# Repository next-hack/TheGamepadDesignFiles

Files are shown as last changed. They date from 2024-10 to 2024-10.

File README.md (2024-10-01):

# TheGamepadDesignFiles
 KiCAD design files for The Gamepad, an open source handheld console based on the Arduino Nano Matter Board.

**Notes**
Please use KiCAD 8.0 or later.
Each item in the schematics has its own part number filled so you can easily create the bill of materials.

Building: see https://next-hack.com/index.php/2024/09/21/the-gamepad-an-open-source-diy-handheld-gaming-console

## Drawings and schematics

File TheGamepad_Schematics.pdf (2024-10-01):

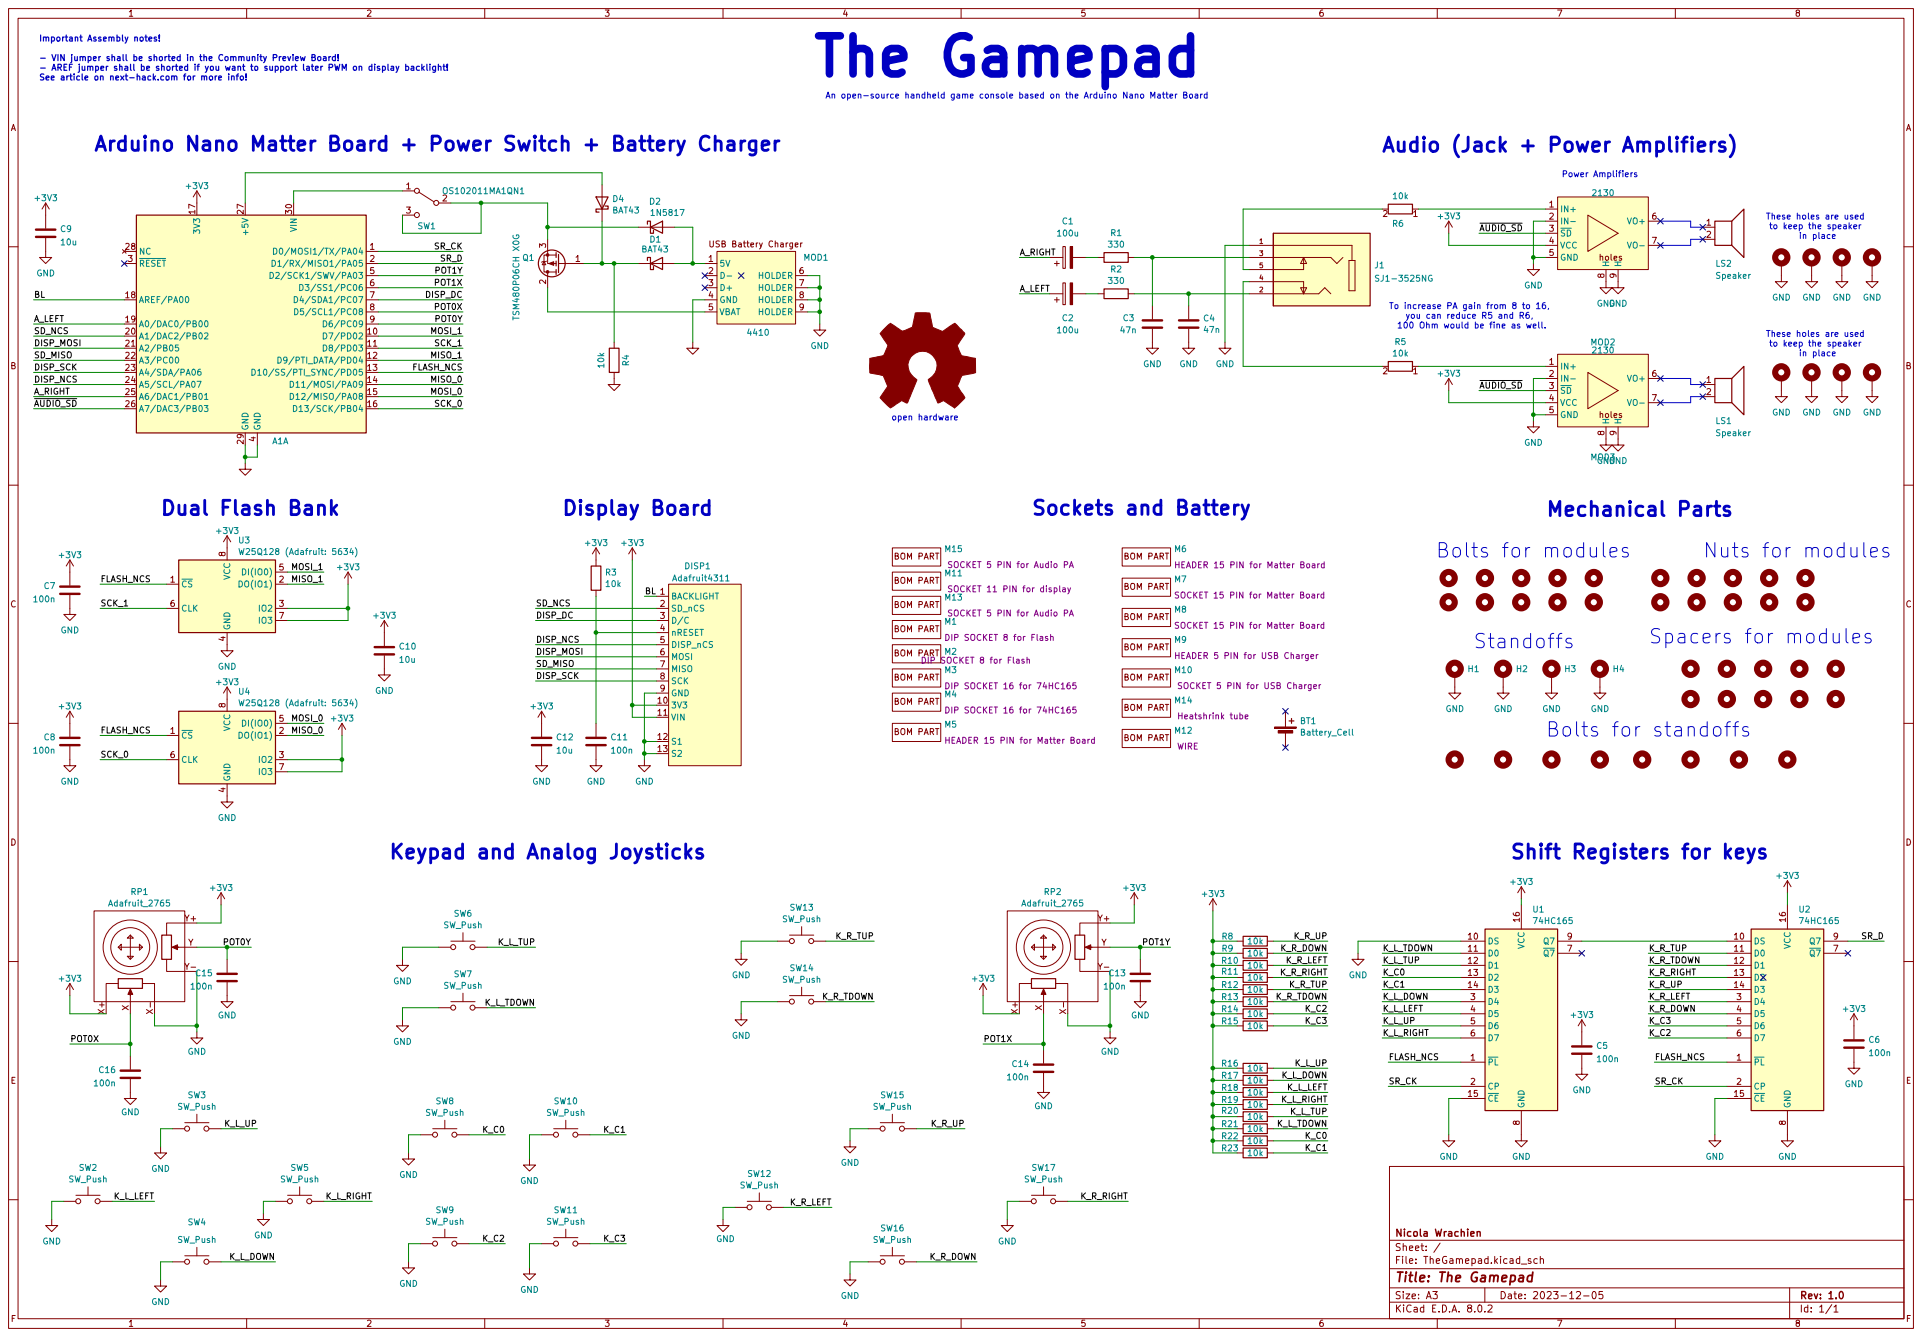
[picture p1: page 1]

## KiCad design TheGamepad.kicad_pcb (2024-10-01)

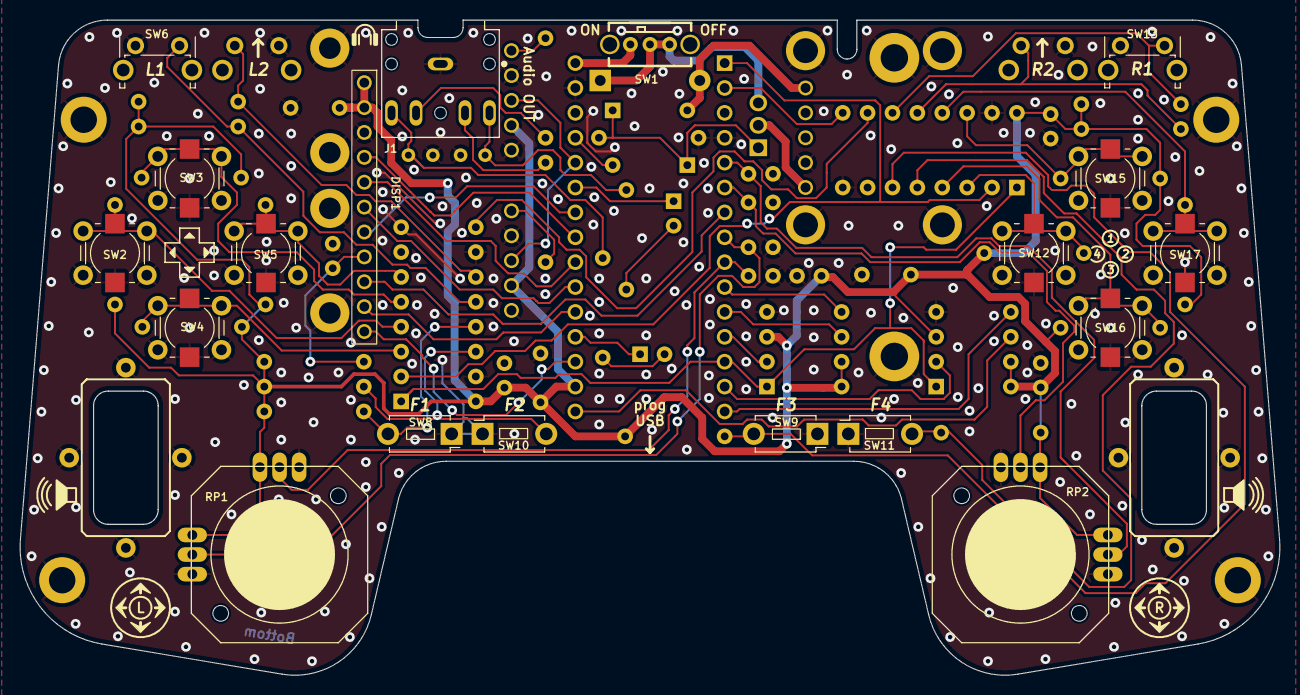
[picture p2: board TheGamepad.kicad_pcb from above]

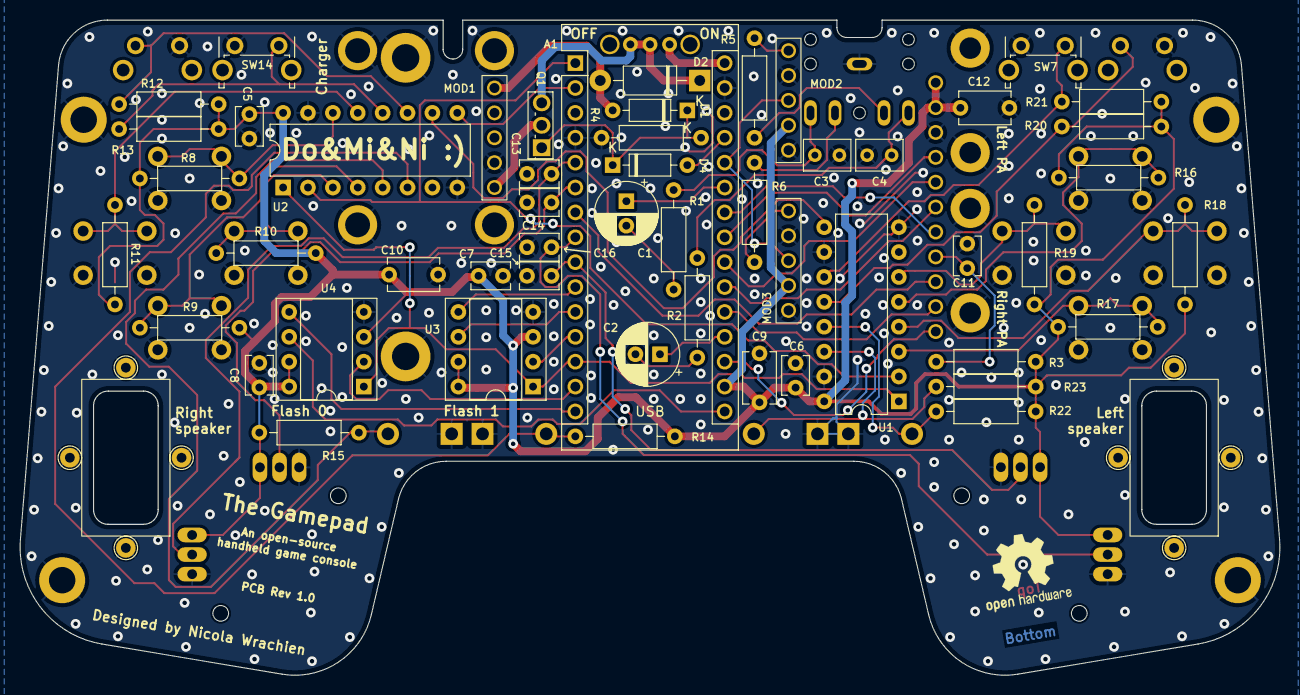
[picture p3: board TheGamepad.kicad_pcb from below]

Board: 2 copper layers, 128.6 x 66.9 mm, 86 parts (61 on the bottom side), 57 nets.

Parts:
A1: Arduino_Nano_Matter_swdio_pins; Arduino_Nano_Matter_WithMountingHoles_TP
C1, C2: 100u; CP_Radial_D6.3mm_P2.50mm
C3, C4: 47n; C_Rect_L4.6mm_W3.0mm_P2.50mm_MKS02_FKP02
C5, C6, C7, C8, C11, C13, C14, C15, C16: 100n; C_Disc_D3.8mm_W2.6mm_P2.50mm
C9, C10, C12: 10u; C_Disc_D5.1mm_W3.2mm_P5.00mm
D1, D4: BAT43; D_DO-35_SOD27_P7.62mm_Horizontal
D2: 1N5817; D_DO-41_SOD81_P10.16mm_Horizontal
DISP1: Adafruit4311
H1, H2, H3, H4: V6516F; MountingHole_2.7mm_M2.5_Pad
H43, H44, H45, H46, H47, H48, H49, H50: MountingHole_Pad; TestPoint_THTPad_D2.0mm_Drill1.0mm
J1: SJ1-3525NG; CUI_SJ1-3525NG
LS1, LS2: Speaker; OWS-091630W50A-8
MOD1: ADAFRUIT_4410
MOD2, MOD3: Adafruit-2130
Q1: TSM480P06CH X0G; TO-251-3_Vertical
R1, R2: 330; R_Axial_DIN0207_L6.3mm_D2.5mm_P10.16mm_Horizontal_ExactSilk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
R3, R4, R5, R6, R8, R9, R10, R11, R12, R13, R14, R15, R16, R17, R18, R19, R20, R21, R22, R23: 10k; R_Axial_DIN0207_L6.3mm_D2.5mm_P10.16mm_Horizontal_ExactSilk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
RP1, RP2: Adafruit_2765
SW1: OS102011MA1QN1
SW2, SW3, SW4, SW5, SW12, SW15, SW16, SW17: SW_Push; Adafruit_PB_3983_SW6x6_DUALCASE
SW6, SW7, SW13, SW14: SW_Push; FSMRA2JH04
SW8, SW9, SW10, SW11: SW_Push; PTS636 SL43 LFS
SYM1: Logo_Open_Hardware_Large; OSHW-Logo2_9.8x8mm_SilkScreen
U1, U2: 74HC165; DIP-16_W7.62mm
U3, U4: W25Q64; ADAFRUIT_QSPI8_DIP

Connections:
+3V3: A1.17 (3V3), C5.1, C6.1, C7.1, C8.1, C9.1, C10.1, C12.1, DISP1.10 (3V3), DISP1.11 (VIN), MOD2.4 (VCC), MOD3.4 (VCC), R3.2, R8.2, R9.2, R10.2, R11.2, R12.2, R13.2, R14.2, R15.2, R16.2, R17.2, R18.2, R19.2, R20.2, R21.2, R22.2, R23.2, RP1.X+, RP1.Y+, RP2.X+, RP2.Y+, U1.16 (VCC), U2.16 (VCC), U3.3 (IO2), U3.7 (IO3), U3.8 (VCC), U4.3 (IO2), U4.7 (IO3), U4.8 (VCC)
/A_LEFT: A1.19 (A0/DAC0/PB00), C2.1
/A_RIGHT: A1.25 (A6/DAC1/PB01), C1.1
/BL: A1.18 (AREF/PA00), DISP1.1 (BACKLIGHT)
/DISP_DC: A1.7 (D4/SDA1/PC07), DISP1.3 (D/C)
/DISP_MOSI: A1.21 (A2/PB05), DISP1.6 (MOSI)
/DISP_NCS: A1.24 (A5/SCL/PA07), DISP1.5 (DISP_nCS)
/DISP_SCK: A1.23 (A4/SDA/PA06), DISP1.8 (SCK)
/FLASH_NCS: A1.13 (D10/SS/PTI_SYNC/PD05), U1.1 (~PL), U2.1 (~PL), U3.1 (~CS), U4.1 (~CS)
/K_C0: R22.1, SW8.2, U1.13 (D2)
/K_C1: R23.1, SW10.2, U1.14 (D3)
/K_C2: R14.1, SW9.2, U2.6 (D7)
/K_C3: R15.1, SW11.2, U2.5 (D6)
/K_L_DOWN: R17.1, SW4.2, U1.3 (D4)
/K_L_LEFT: R18.1, SW2.2, U1.4 (D5)
/K_L_RIGHT: R19.1, SW5.2, U1.6 (D7)
/K_L_TDOWN: R21.1, SW7.2, U1.11 (D0)
/K_L_TUP: R20.1, SW6.2, U1.12 (D1)
/K_L_UP: R16.1, SW3.2, U1.5 (D6)
/K_R_DOWN: R9.1, SW16.2, U2.4 (D5)
/K_R_LEFT: R10.1, SW12.2, U2.3 (D4)
/K_R_RIGHT: R11.1, SW17.2, U2.13 (D2)
/K_R_TDOWN: R13.1, SW14.2, U2.12 (D1)
/K_R_TUP: R12.1, SW13.2, U2.11 (D0)
/K_R_UP: R8.1, SW15.2, U2.14 (D3)
/MISO_0: A1.14 (D11/MOSI/PA09), U4.2 (DO(IO1))
/MISO_1: A1.12 (D9/PTI_DATA/PD04), U3.2 (DO(IO1))
/MOSI_0: A1.15 (D12/MISO/PA08), U4.5 (DI(IO0))
/MOSI_1: A1.10 (D7/PD02), U3.5 (DI(IO0))
/POT0X: A1.8 (D5/SCL1/PC08), C16.1, RP1.X
/POT0Y: A1.9 (D6/PC09), C15.1, RP1.Y
/POT1X: A1.6 (D3/SS1/PC06), C14.1, RP2.X
/POT1Y: A1.5 (D2/SCK1/SWV/PA03), C13.1, RP2.Y
/SCK_0: A1.16 (D13/SCK/PB04), U4.6 (CLK)
/SCK_1: A1.11 (D8/PD03), U3.6 (CLK)
/SD_MISO: A1.22 (A3/PC00), DISP1.7 (MISO)
/SD_NCS: A1.20 (A1/DAC2/PB02), DISP1.2 (SD_nCS)
/SR_CK: A1.1 (D0/MOSI1/TX/PA04), U1.2 (CP), U2.2 (CP)
/SR_D: A1.2 (D1/RX/MISO1/PA05), U2.9 (Q7)
/~AUDIO_SD: A1.26 (A7/DAC3/PB03), MOD2.3 (~SD), MOD3.3 (~SD)
GND: A1.4 (GND), A1.29 (GND), C3.2, C4.2, C5.2, C6.2, C7.2, C8.2, C9.2, C10.2, C11.2, C12.2, C13.2, C14.2, C15.2, C16.2, DISP1.9 (GND), DISP1.12 (S1), DISP1.13 (S2), H1.1, H2.1, H3.1, H4.1, H43.1, H44.1, H45.1, H46.1, H47.1, H48.1, H49.1, H50.1, J1.1, MOD1.4 (GND), MOD1.6 (HOLDER), MOD2.2 (IN-), MOD2.5 (GND), MOD2.8 (H), MOD2.9 (H), MOD3.2 (IN-), MOD3.5 (GND), MOD3.8 (H), MOD3.9 (H), R4.2, RP1.X-, RP1.Y-, RP2.X-, RP2.Y-, SW2.1, SW3.1, SW4.1, SW5.1, SW6.1, SW7.1, SW8.1, SW9.1, SW10.1, SW11.1, SW12.1, SW13.1, SW14.1, SW15.1, SW16.1, SW17.1, U1.8 (GND), U1.10 (DS), U1.15 (~CE), U2.8 (GND), U2.15 (~CE), U3.4 (GND), U4.4 (GND)
unnamed: A1.27 (+5V), D4.2 (A)
unnamed: A1.30 (VIN), SW1.1 (A)
unnamed: C1.2, R1.1
unnamed: C2.2, R2.1
unnamed: C3.1, J1.3, R1.2
unnamed: C4.1, J1.2, R2.2
unnamed: D1.2 (A), D2.2 (A), MOD1.1 (5V)
unnamed: D1.1 (K), D4.1 (K), Q1.1 (G), R4.1
unnamed: D2.1 (K), Q1.3 (S), SW1.2 (B), SW1.3 (C)
unnamed: C11.1, DISP1.4 (nRESET), R3.1
unnamed: J1.4, R5.2
unnamed: J1.5, R6.2
unnamed: MOD1.5 (VBAT), Q1.2 (D)
unnamed: MOD2.1 (IN+), R5.1
unnamed: MOD3.1 (IN+), R6.1
unnamed: U1.9 (Q7), U2.10 (DS)
